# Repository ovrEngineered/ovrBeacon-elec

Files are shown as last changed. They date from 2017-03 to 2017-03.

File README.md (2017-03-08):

# ovrBeacon-elec

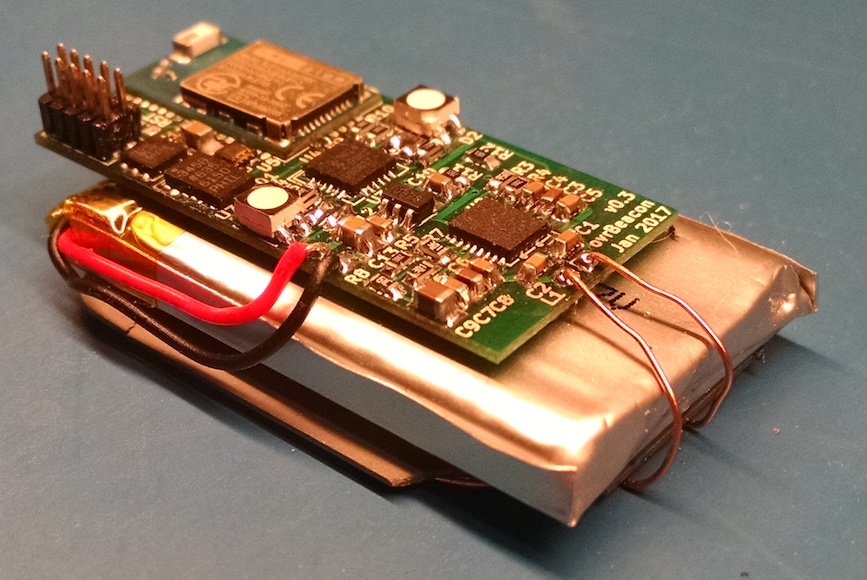
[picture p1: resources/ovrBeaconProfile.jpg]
ovrBeacon Profile


This project contains an open-source implementation of a Bluetooth Low Energy sensor beacon.
The beacon has the following features:
 - Integrated temperature sensor
 - Integrated light sensor
 - Integrated accelerometer
 - Remotely controlled LEDs
 - Wireless charging via Qi standard
 
Note: this repository contains the schematics and PCB design. The firmware repository is located [here](https://github.com/ovrEngineered/ovrBeacon-fw).

## Physical Description
ovrBeacon Dimensions

| Height | Width | Depth w/ programming header | Depth w/o programming header |
| --- | --- | --- | --- |
| 1.85" (47mm) | 1.06" (27mm) | 0.57" (14.48mm) | 0.41" (10.41mm) |

## Parameters
| Parameter | Min  | Typical | Max | Units |
| --- | ---- | --- | --- | ----- |
| Temperature accuracy**  | - | +/- 1 | - | °C |
| Acceleration range | -16  | - | +16 | g |
| Acceleration resolution | - | 4 | - | mg |
| Light sensitivity | 0.01 | - | 64,000 | lux |
| Battery Capacity*** | - | 500 | - | mAh.  |
** accuracy can be increased with pin-compatible parts 

*** capacity can be increased with replacement batteries

## Links
 * [Schematic PDF](output/ovrBeacon_schematic.pdf)
 * [PCB Layout PDF](output/ovrBeacon_layout.pdf)

## Built With
 * [KiCad](http://kicad-pcb.org/)

## Versioning
We use [SemVer](http://semver.org/) for versioning. For the versions available, see the [tags on this repository](https://github.com/ovrEngineered/ovrBeacon-elec/tags). 

## License
This project is licensed under the MIT License:

> Permission is hereby granted, free of charge, to any person obtaining a copy of this software and associated documentation files (the "Software"), to deal in the Software without restriction, including without limitation the rights to use, copy, modify, merge, publish, distribute, sublicense, and/or sell copies of the Software, and to permit persons to whom the Software is furnished to do so, subject to the following conditions:
>
> The above copyright notice and this permission notice shall be included in all copies or substantial portions of the Software.
>
> THE SOFTWARE IS PROVIDED "AS IS", WITHOUT WARRANTY OF ANY KIND, EXPRESS OR IMPLIED, INCLUDING BUT NOT LIMITED TO THE WARRANTIES OF MERCHANTABILITY, FITNESS FOR A PARTICULAR PURPOSE AND NONINFRINGEMENT. IN NO EVENT SHALL THE AUTHORS OR COPYRIGHT HOLDERS BE LIABLE FOR ANY CLAIM, DAMAGES OR OTHER LIABILITY, WHETHER IN AN ACTION OF CONTRACT, TORT OR OTHERWISE, ARISING FROM, OUT OF OR IN CONNECTION WITH THE SOFTWARE OR THE USE OR OTHER DEALINGS IN THE SOFTWARE.

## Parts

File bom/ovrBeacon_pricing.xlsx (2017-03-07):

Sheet: Stock
Reference | Manufacturer | Man. Part Num. | Supplier | Supplier Part Num. | Quantity | Price (qty 1) | Subtotal (qty 1) | Price (qty 1000) | Subtotal (qty 1000)
U1 | BlueGiga | BLE113-A-M256K | Digi-Key | 1446-1035-1-ND | 1 | $11.49 | $11.49 | $6.948850 | $6.948850
R1 R5 R4 R9 R10 | Vishay_Dale | CRCW060310K0FKEA | Digi-Key | 541-10.0KHCT-ND | 5 | $0.10 | $0.50 | $0.003610 | $0.018050
C1 | TDK Corporation | C1608X7R1E154K080AA | Digi-Key | 445-5190-1-ND | 1 | $0.10 | $0.10 | $0.015150 | $0.015150
C2 | Murata | GRM188R71H222KA01D | Digi-Key | 490-1500-1-ND | 1 | $0.10 | $0.10 | $0.008820 | $0.008820
C6 C5 | Murata | GRM188R71E103KA01D | Digi-Key | 490-1520-1-ND | 2 | $0.10 | $0.20 | $0.005760 | $0.011520
C3 C8 | TDK Corporation | C1608X5R1E474K080AC | Digi-Key | 445-5144-1-ND | 2 | $0.15 | $0.30 | $0.027780 | $0.055560
C4 C7 | Murata | GRM188R71E223KA01D | Digi-Key | 490-9761-1-ND | 2 | $0.10 | $0.20 | $0.015450 | $0.030900
C9 | Murata | GRT21BR61E226ME13L | Digi-Key | 490-12389-1-ND | 1 | $0.58 | $0.58 | $0.187250 | $0.187250
R8 | Yageo | RC0603FR-0742K2L | Digi-Key | 311-42.2KHRCT-ND | 1 | $0.10 | $0.10 | $0.002330 | $0.002330
R6 R7 | Yageo | RC0603FR-07300RL | Digi-Key | 311-300HRCT-ND | 2 | $0.10 | $0.20 | $0.002330 | $0.004660
R3 | Yageo | RC0603FR-07953RL | Digi-Key | 311-953HRCT-ND | 1 | $0.10 | $0.10 | $0.002330 | $0.002330
C13 C11 | Murata | GRM21BR71A105KA01L | Digi-Key | 490-1695-1-ND | 2 | $0.11 | $0.22 | $0.020830 | $0.041660
C12 C10 | Murata | GRM188R71C104KA01D | Digi-Key | 490-1532-1-ND | 2 | $0.10 | $0.20 | $0.004730 | $0.009460
R14 R15 R16 R17 R18 R19 | Vishay_Dale | CRCW0603120RFKEA | Digi-Key | 541-120HCT-ND | 6 | $0.10 | $0.60 | $0.055400 | $0.332400
R11 | Vishay_Dale | CRCW060312K0FKEA | Digi-Key | 541-12.0KHCT-ND | 1 | $0.10 | $0.10 | $0.005540 | $0.005540
R12 | Vishay_Dale | CRCW06035K10FKEA | Digi-Key | 541-5.10KHCT-ND | 1 | $0.10 | $0.10 | $0.005540 | $0.005540
D1 D2 | Cree Inc. | CLV1A-FKB-CK1N1G1BB7R4S3 | Digi-Key | CLV1A-FKB-CK1N1G1BB7R4S3CT-ND | 2 | $0.74 | $1.48 | $0.442200 | $0.884400
L1 | Vishay Dale | IWAS3827ECEB100J50 | Digi-Key | 541-1695-ND | 1 | $3.39 | $3.39 | $1.695000 | $1.695000
U2 | Texas Instruments | BQ51050BRHLR | Digi-Key | 296-35066-1-ND | 1 | $4.23 | $4.23 | $2.116800 | $2.116800
U3 | Torex Semiconductor | XC6210B332MR-G | Digi-Key | 893-1075-1-ND | 1 | $0.88 | $0.88 | $0.351020 | $0.351020
U4 | NXP | PCA9624BS | Digi-Key | 568-5304-1-ND | 1 | $1.91 | $1.91 | $0.940910 | $0.940910
U5 | Lite-On | LTR-329ALS-01 | Digi-Key | 160-2160-1-ND | 1 | $1.08 | $1.08 | $0.431060 | $0.431060
U7 | Analog Devices | ADXL345BCCZ-RL | Digi-Key | ADXL345BCCZ-RLCT-ND | 1 | $7.86 | $7.86 | $4.459460 | $4.459460
J1 | Amphenol | 20021111-00010T4LF | Digi-Key | 609-3712-ND | 1 | $0.64 | $0.64 | $0.330990 | $0.330990
U6 | Silicon Labs | SI7050-A20-IM | Digi-Key | 336-3118-5-ND | 1 | $1.25 | $1.25 | $0.939300 | $0.939300
Battery |  |  |  |  | 1
PCB |  |  |  |  | 1 | $1.00 | $1.00 | $1.000000 | $1.000000
Assembly |  |  |  |  | 1 |  |  | $2.000000 | $2.000000
 |  |  |  |  |  | Total: | $38.81 |  | $22.83

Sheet: Variant - No Accelerometer
Reference | Manufacturer | Man. Part Num. | Supplier | Supplier Part Num. | Quantity | Price (qty 1) | Subtotal (qty 1) | Price (qty 1000) | Subtotal (qty 1000)
U1 | BlueGiga | BLE113-A-M256K | Digi-Key | 1446-1035-1-ND | 1 | $11.49 | $11.49 | $6.948850 | $6.948850
R1 R5 R4 R9 R10 | Vishay_Dale | CRCW060310K0FKEA | Digi-Key | 541-10.0KHCT-ND | 5 | $0.10 | $0.50 | $0.003610 | $0.018050
C1 | TDK Corporation | C1608X7R1E154K080AA | Digi-Key | 445-5190-1-ND | 1 | $0.10 | $0.10 | $0.015150 | $0.015150
C2 | Murata | GRM188R71H222KA01D | Digi-Key | 490-1500-1-ND | 1 | $0.10 | $0.10 | $0.008820 | $0.008820
C6 C5 | Murata | GRM188R71E103KA01D | Digi-Key | 490-1520-1-ND | 2 | $0.10 | $0.20 | $0.005760 | $0.011520
C3 C8 | TDK Corporation | C1608X5R1E474K080AC | Digi-Key | 445-5144-1-ND | 2 | $0.15 | $0.30 | $0.027780 | $0.055560
C4 C7 | Murata | GRM188R71E223KA01D | Digi-Key | 490-9761-1-ND | 2 | $0.10 | $0.20 | $0.015450 | $0.030900
C9 | Murata | GRT21BR61E226ME13L | Digi-Key | 490-12389-1-ND | 1 | $0.58 | $0.58 | $0.187250 | $0.187250
R8 | Yageo | RC0603FR-0742K2L | Digi-Key | 311-42.2KHRCT-ND | 1 | $0.10 | $0.10 | $0.002330 | $0.002330
R6 R7 | Yageo | RC0603FR-07300RL | Digi-Key | 311-300HRCT-ND | 2 | $0.10 | $0.20 | $0.002330 | $0.004660
R3 | Yageo | RC0603FR-07953RL | Digi-Key | 311-953HRCT-ND | 1 | $0.10 | $0.10 | $0.002330 | $0.002330
C13 C11 | Murata | GRM21BR71A105KA01L | Digi-Key | 490-1695-1-ND | 2 | $0.11 | $0.22 | $0.020830 | $0.041660
C12 C10 | Murata | GRM188R71C104KA01D | Digi-Key | 490-1532-1-ND | 2 | $0.10 | $0.20 | $0.004730 | $0.009460
R14 R15 R16 R17 R18 R19 | Vishay_Dale | CRCW0603120RFKEA | Digi-Key | 541-120HCT-ND | 6 | $0.10 | $0.60 | $0.055400 | $0.332400
R11 | Vishay_Dale | CRCW060312K0FKEA | Digi-Key | 541-12.0KHCT-ND | 1 | $0.10 | $0.10 | $0.005540 | $0.005540
R12 | Vishay_Dale | CRCW06035K10FKEA | Digi-Key | 541-5.10KHCT-ND | 1 | $0.10 | $0.10 | $0.005540 | $0.005540
D1 D2 | Cree Inc. | CLV1A-FKB-CK1N1G1BB7R4S3 | Digi-Key | CLV1A-FKB-CK1N1G1BB7R4S3CT-ND | 2 | $0.74 | $1.48 | $0.442200 | $0.884400
L1 | Vishay Dale | IWAS3827ECEB100J50 | Digi-Key | 541-1695-ND | 1 | $3.39 | $3.39 | $1.695000 | $1.695000
U2 | Texas Instruments | BQ51050BRHLR | Digi-Key | 296-35066-1-ND | 1 | $4.23 | $4.23 | $2.116800 | $2.116800
U3 | Torex Semiconductor | XC6210B332MR-G | Digi-Key | 893-1075-1-ND | 1 | $0.88 | $0.88 | $0.351020 | $0.351020
U4 | NXP | PCA9624BS | Digi-Key | 568-5304-1-ND | 1 | $1.91 | $1.91 | $0.940910 | $0.940910
U5 | Lite-On | LTR-329ALS-01 | Digi-Key | 160-2160-1-ND | 1 | $1.08 | $1.08 | $0.431060 | $0.431060
U7 | Analog Devices | ADXL345BCCZ-RL | Digi-Key | ADXL345BCCZ-RLCT-ND | 0 | $7.86 | $0.00 | $4.459460 | $0.000000
J1 | Amphenol | 20021111-00010T4LF | Digi-Key | 609-3712-ND | 1 | $0.64 | $0.64 | $0.330990 | $0.330990
U6 | Silicon Labs | SI7050-A20-IM | Digi-Key | 336-3118-5-ND | 1 | $1.25 | $1.25 | $0.939300 | $0.939300
Battery |  |  |  |  | 1
PCB |  |  |  |  | 1 | $1.00 | $1.00 | $1.000000 | $1.000000
Assembly |  |  |  |  | 1 |  |  | $2.000000 | $2.000000
 |  |  |  |  |  | Total: | $30.95 |  | $18.37

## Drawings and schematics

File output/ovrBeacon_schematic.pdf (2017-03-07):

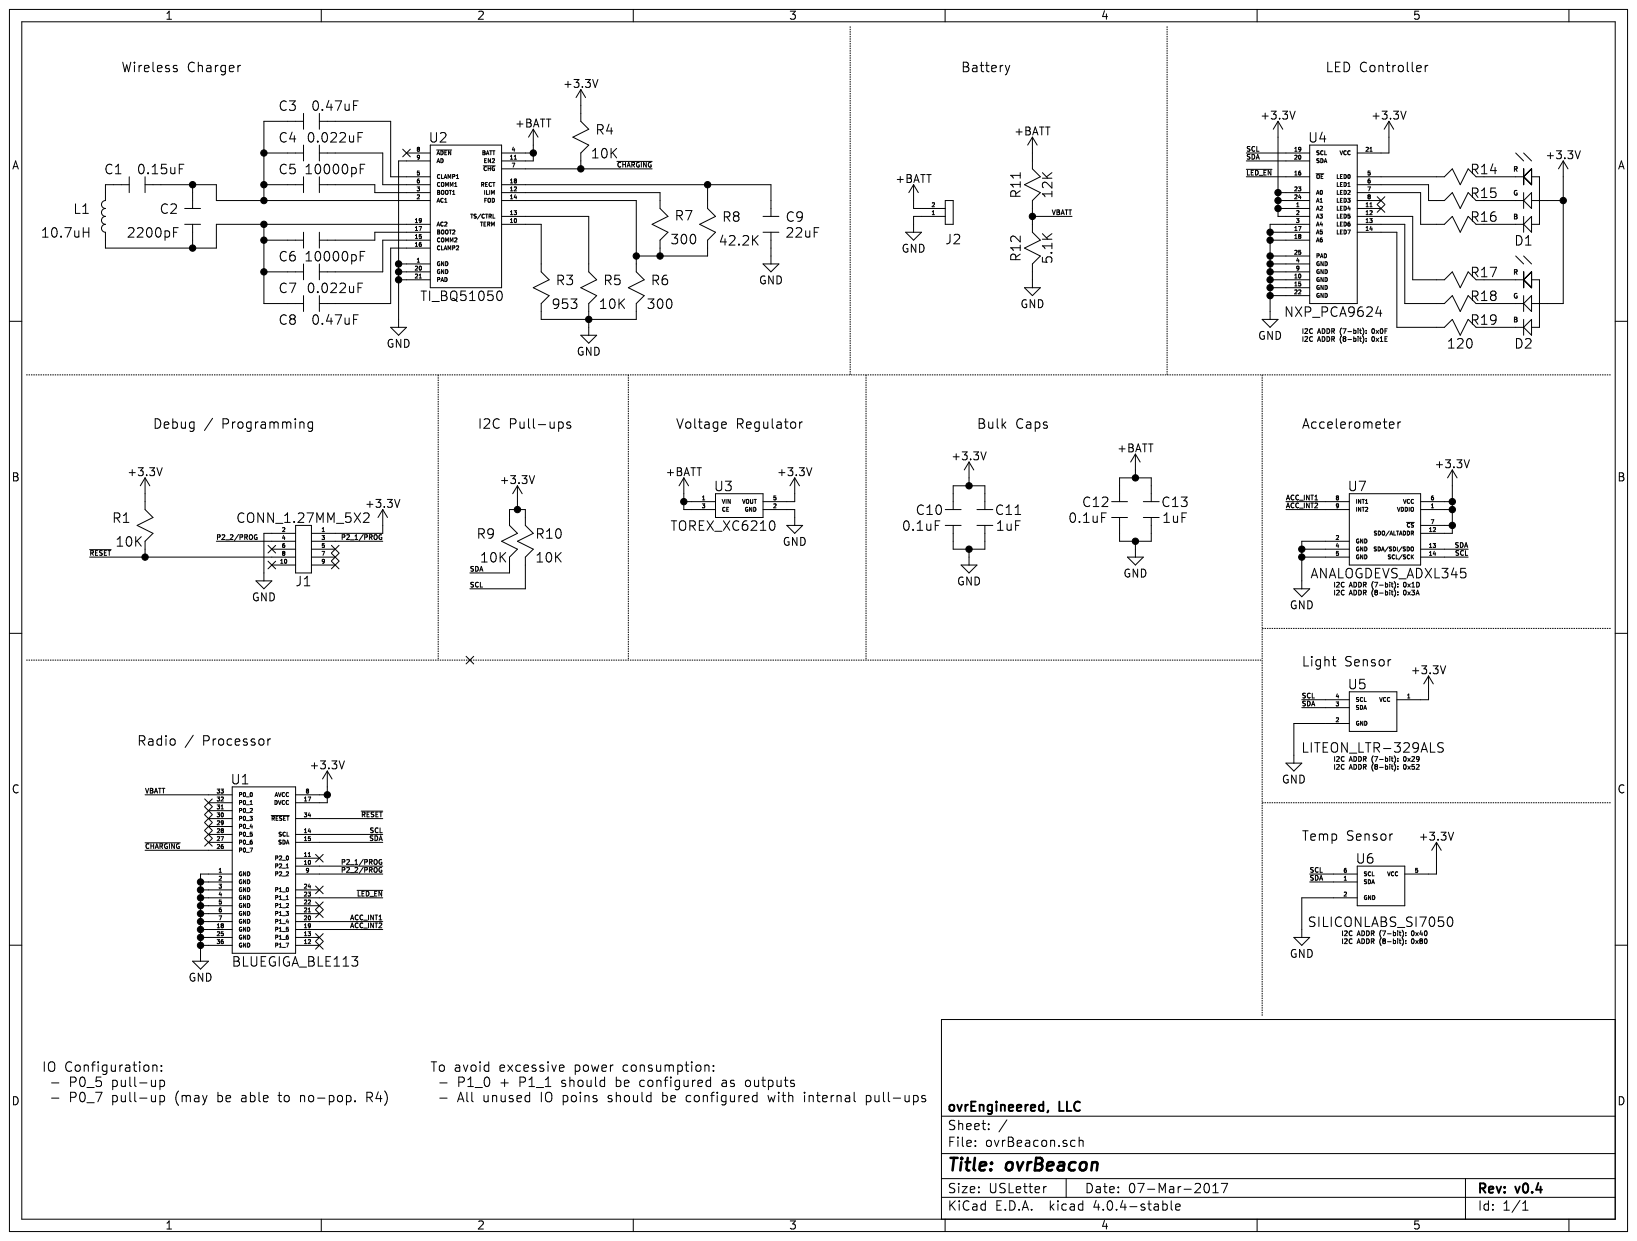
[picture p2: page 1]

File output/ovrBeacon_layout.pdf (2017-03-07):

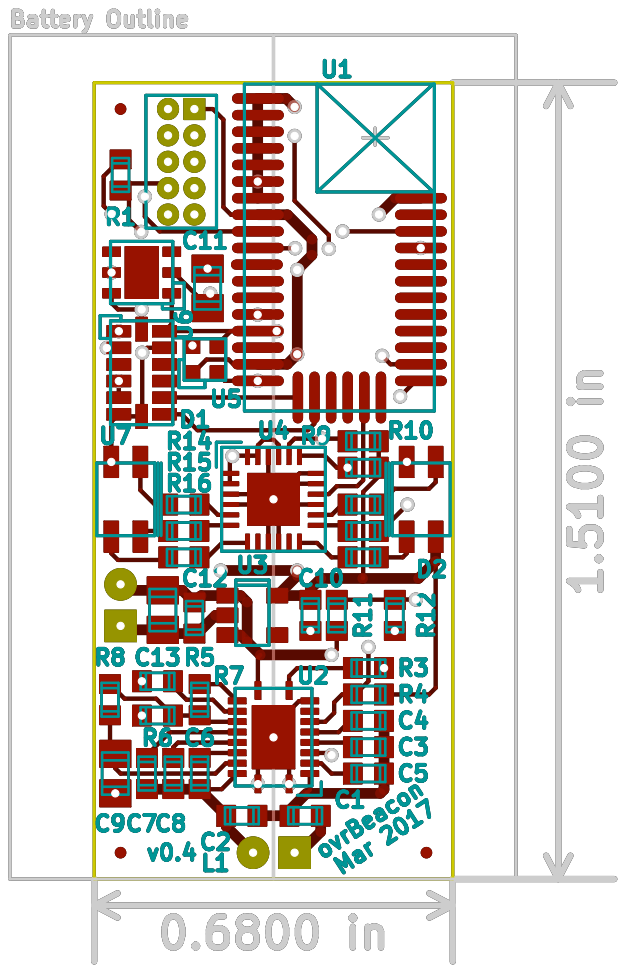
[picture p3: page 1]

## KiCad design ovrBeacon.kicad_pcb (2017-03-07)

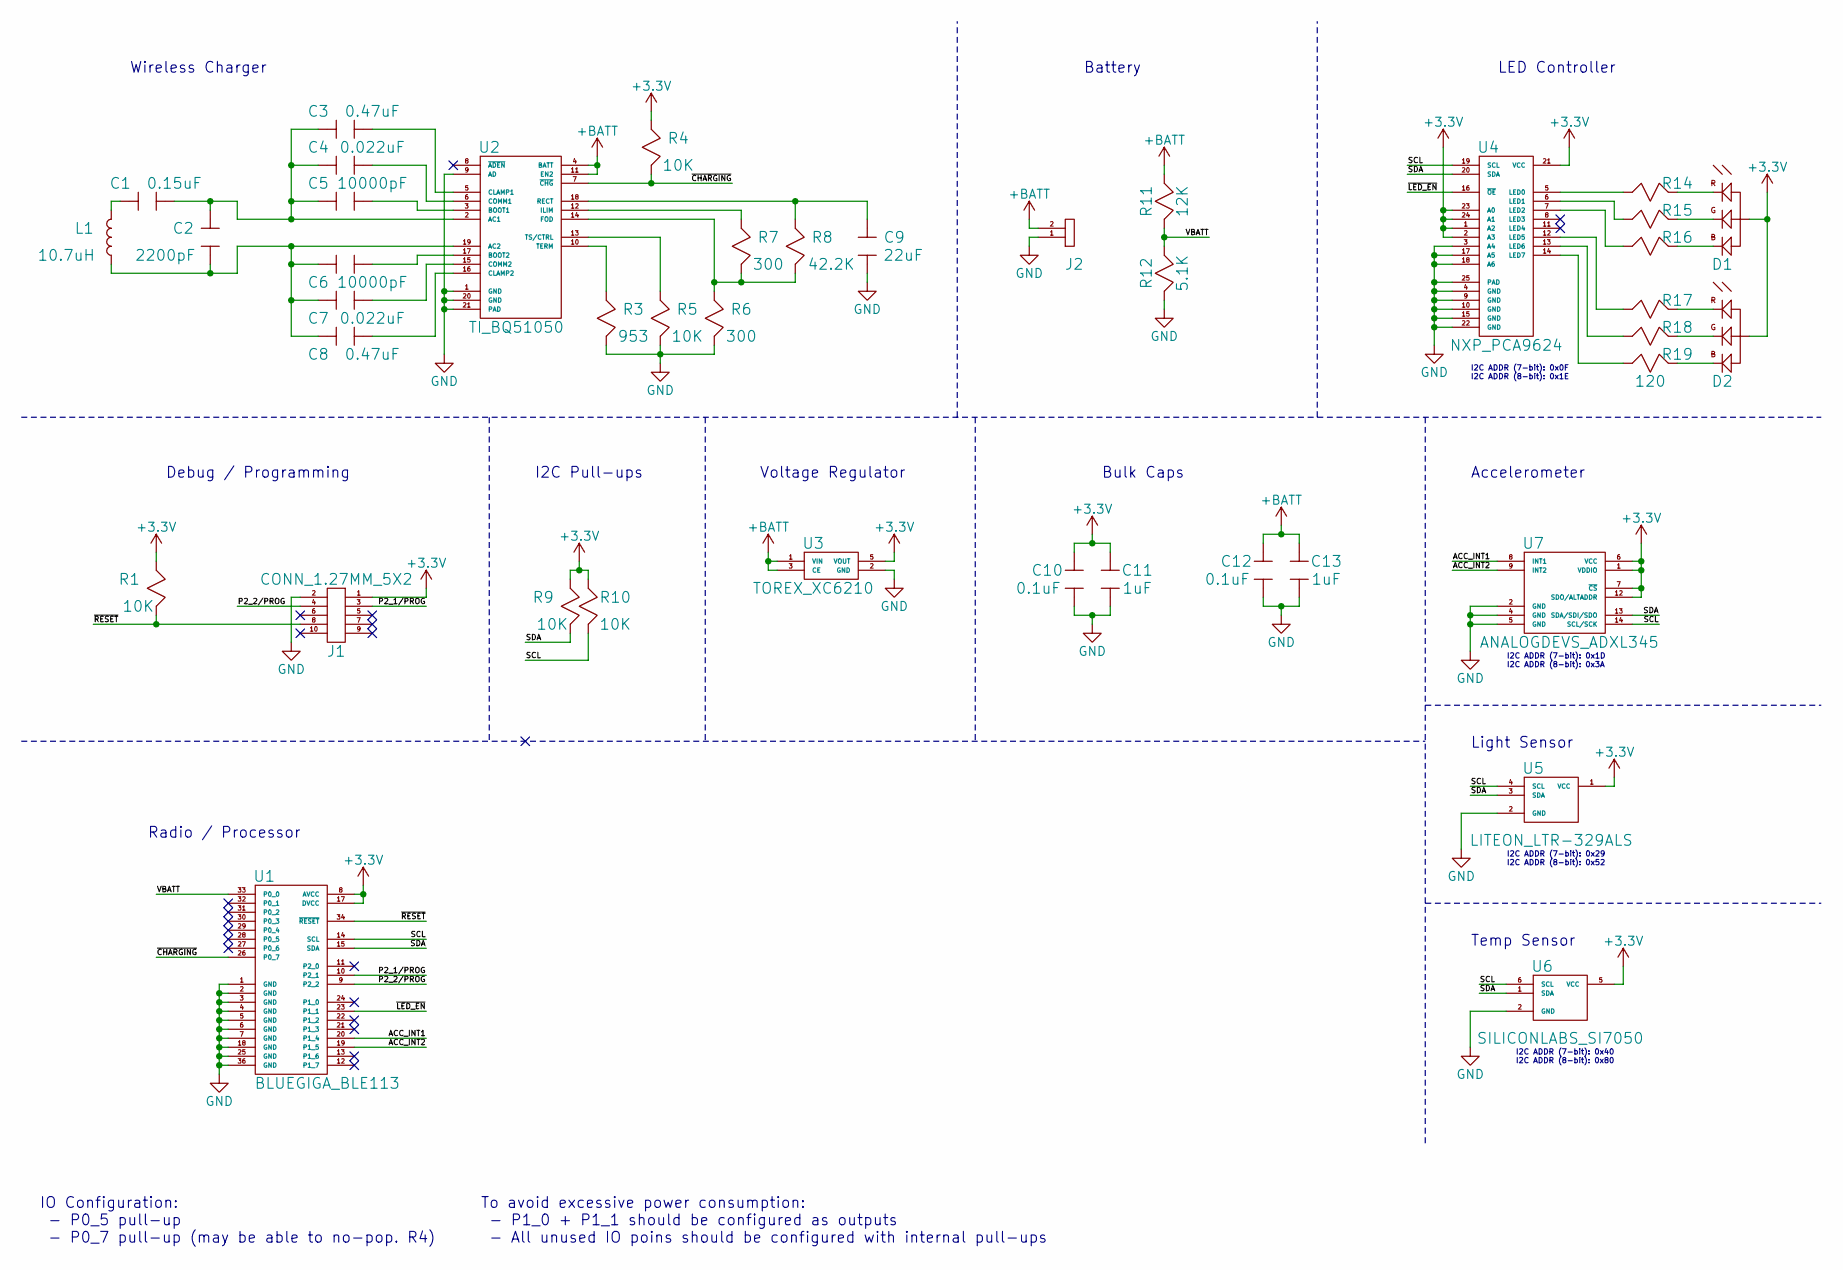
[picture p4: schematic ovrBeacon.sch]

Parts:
C1: C_0.15uF_25v_0603; C_0603; Man. Part Num. C1608X7R1E154K080AA
C2: C_2200pF_50v_0603; C_0603; Man. Part Num. GRM188R71H222KA01D
C3, C8: C_0.47uF_25v_0603; C_0603; Man. Part Num. C1608X5R1E474K080AC
C4, C7: C_0.022uF_25v_0603; C_0603; Man. Part Num. GRM188R71E223KA01D
C5, C6: C_10000pF_25v_0603; C_0603; Man. Part Num. GRM188R71E103KA01D
C9: C_22uF_25v_0805; C_0805; Man. Part Num. GRT21BR61E226ME13L
C10, C12: C_0.1uF_10v_0603; C_0603; Man. Part Num. GRM188R71C104KA01D
C11, C13: C_1uF_10v_0805; C_0805; Man. Part Num. GRM21BR71A105KA01L
D1, D2: CREE_CLV1A_FKB; Man. Part Num. CLV1A-FKB-CK1N1G1BB7R4S3
J1: CONN_1.27MM_5X2; 20021111-00010T4LF; Man. Part Num. 20021111-00010T4LF
J2: CONN_2MM_2; SIP_2MM_2; Man. Part Num. 951102-8622-AR
L1: QIRX_10.7uH; SIP_2MM_2; Man. Part Num. IWAS3827ECEB100J50
R1, R4, R5, R9, R10: R_10K_1%_0603; R_0603; Man. Part Num. CRCW060310K0FKEA
R3: R_953_1%_0603; R_0603; Man. Part Num. RC0603FR-07953RL
R6, R7: R_300_1%_0603; R_0603; Man. Part Num. RC0603FR-07300RL
R8: R_42.2K_1%_0603; R_0603; Man. Part Num. RC0603FR-0742K2L
R11: R_12K_1%_0603; R_0603; Man. Part Num. CRCW060312K0FKEA
R12: R_5.1K_1%_0603; R_0603; Man. Part Num. CRCW06035K10FKEA
R14, R15, R16, R17, R18, R19: R_120_1%_0603; R_0603; Man. Part Num. CRCW0603120RFKEA
U1: BLUEGIGA_BLE113; BLE113; Man. Part Num. BLE113-A-M256K
U2: TI_BQ51050; Man. Part Num. BQ51050BRHLR
U3: TOREX_XC6210; SOT-25-5; Man. Part Num. XC6210B332MR-G
U4: NXP_PCA9624; Man. Part Num. PCA9624BS,118
U5: LITEON_LTR-329ALS; Man. Part Num. LTR-329ALS-01
U6: SILICONLABS_SI7050; Man. Part Num. SI7050-A20-IM
U7: ANALOGDEVS_ADXL345; Man. Part Num. ADXL345BCCZ-RL

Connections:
+3V3: C10.1, C11.1, D1.2 (ANODE), D2.2 (ANODE), J1.1, R1.1, R4.1, R9.1, R10.1, U1.8 (AVCC), U1.17 (DVCC), U3.5 (VOUT), U4.1 (A2), U4.2 (A3), U4.21 (VCC), U4.23 (A0), U4.24 (A1), U5.1 (VCC), U6.5 (VCC), U7.1 (VDDIO), U7.6 (VCC), U7.7 (~CS), U7.12 (SDO/ALTADDR)
+BATT: C12.1, C13.1, J2.2, R11.1, U2.4 (BATT), U2.11 (EN2), U3.1 (VIN), U3.3 (CE)
/ACC_INT1: U1.20 (P1_4), U7.8 (INT1)
/ACC_INT2: U1.19 (P1_5), U7.9 (INT2)
/P2_1/PROG: J1.3, U1.10 (P2_1)
/P2_2/PROG: J1.4, U1.9 (P2_2)
/SCL: R10.2, U1.14 (SCL), U4.19 (SCL), U5.4 (SCL), U6.6 (SCL), U7.14 (SCL/SCK)
/SDA: R9.2, U1.15 (SDA), U4.20 (SDA), U5.3 (SDA), U6.1 (SDA), U7.13 (SDA/SDI/SDO)
/VBATT: R11.2, R12.1, U1.33 (P0_0)
/~CHARGING: R4.2, U1.26 (P0_7), U2.7 (~CHG)
/~LED_EN: U1.23 (P1_1), U4.16 (~OE)
/~RESET: J1.8, R1.2, U1.34 (~RESET)
GND: C9.2, C10.2, C11.2, C12.2, C13.2, J1.2, J2.1, R3.2, R5.2, R6.2, R12.2, U1.1 (GND), U1.2 (GND), U1.3 (GND), U1.4 (GND), U1.5 (GND), U1.6 (GND), U1.7 (GND), U1.18 (GND), U1.25 (GND), U1.36 (GND), U2.1 (GND), U2.9 (AD), U2.20 (GND), U2.21 (PAD), U3.2 (GND), U4.3 (A4), U4.4 (GND), U4.9 (GND), U4.10 (GND), U4.15 (GND), U4.17 (A5), U4.18 (A6), U4.22 (GND), U4.25 (PAD), U5.2 (GND), U6.2 (GND), U7.2 (GND), U7.4 (GND), U7.5 (GND)
unnamed: C1.1, L1.1
unnamed: C1.2, C2.1, C3.1, C4.1, C5.1, U2.2 (AC1)
unnamed: C2.2, C6.1, C7.1, C8.1, L1.2, U2.19 (AC2)
unnamed: C3.2, U2.5 (CLAMP1)
unnamed: C4.2, U2.6 (COMM1)
unnamed: C5.2, U2.3 (BOOT1)
unnamed: C6.2, U2.17 (BOOT2)
unnamed: C7.2, U2.15 (COMM2)
unnamed: C8.2, U2.16 (CLAMP2)
unnamed: C9.1, R8.1, U2.18 (RECT)
unnamed: D1.1 (CATHODE_RED), R14.2
unnamed: D1.3 (CATHODE_BLUE), R16.2
unnamed: D1.4 (CATHOD_GREEN), R15.2
unnamed: D2.1 (CATHODE_RED), R17.2
unnamed: D2.3 (CATHODE_BLUE), R19.2
unnamed: D2.4 (CATHOD_GREEN), R18.2
unnamed: R3.1, U2.10 (TERM)
unnamed: R5.1, U2.13 (TS/CTRL)
unnamed: R6.1, R7.1, R8.2, U2.14 (FOD)
unnamed: R7.2, U2.12 (ILIM)
unnamed: R14.1, U4.5 (LED0)
unnamed: R15.1, U4.6 (LED1)
unnamed: R16.1, U4.7 (LED2)
unnamed: R17.1, U4.12 (LED5)
unnamed: R18.1, U4.13 (LED6)
unnamed: R19.1, U4.14 (LED7)

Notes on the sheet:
Debug / Programming
Radio / Processor
I2C ADDR (7-bit): 0x29 I2C ADDR (8-bit): 0x52
I2C ADDR (7-bit): 0x40 I2C ADDR (8-bit): 0x80
I2C ADDR (7-bit): 0x1D I2C ADDR (8-bit): 0x3A
I2C ADDR (7-bit): 0x0F I2C ADDR (8-bit): 0x1E
I2C Pull-ups
Wireless Charger
Battery
LED Controller
Accelerometer
Light Sensor
Temp Sensor
Voltage Regulator
Bulk Caps
To avoid excessive power consumption: - P1_0 + P1_1 should be configured as outputs - All unused IO poins should be configured with internal pull-ups
IO Configuration: - P0_5 pull-up - P0_7 pull-up (may be able to no-pop. R4)

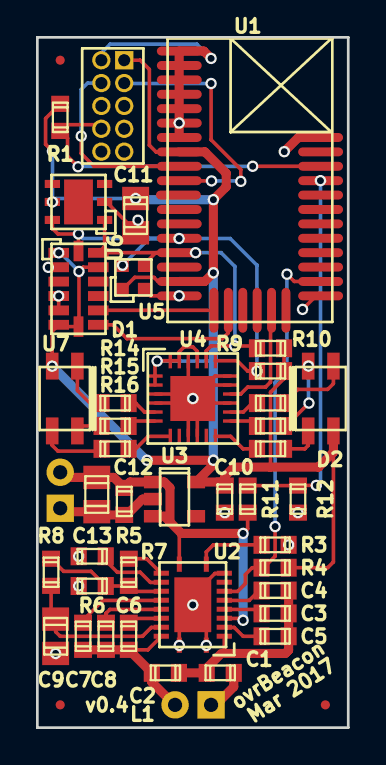
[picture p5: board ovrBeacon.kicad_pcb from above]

Board: 2 copper layers, 17.3 x 38.4 mm, 45 parts (0 on the bottom side), 39 nets.

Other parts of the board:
FID1, FID2, FID3: fiducial

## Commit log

2016-07-31 added KiCAD externals
2017-01-04 initial commit of version 0.3…passed DFM, waiting for manufacture review
    [ovrBeacon-B.Cu.gbl, ovrBeacon-B.Mask.gbs, ovrBeacon-B.SilkS.gbo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]
2017-01-12 As manufactured
    [BOM - ovrBeacon.ods, BillOfMaterials.csv]
2017-02-27 Moved BOM, added pricing, added schematic and layout PDF
    [ovrBeacon_BOM.csv, ovrBeacon_pricing.xlsx]
2017-03-07 Fixed redlines from v0.3, added fiducials for pick and place…getting ready to start adjusting component centers for pick and place
    [ovrBeacon.kicad_pcb, ovrBeacon.sch]
2017-03-07 Adjusted component centers and orientation for pick and place
    [ovrBeacon.kicad_pcb]
2017-03-07 ready for fabrication w/ fiducials, redlines from v0.3, and pick and place file
    [ovrBeacon-B.Cu.gbl, ovrBeacon-B.Mask.gbs, ovrBeacon-B.SilkS.gbo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]
2017-03-07 Updated pricing document w/ variants
    [ovrBeacon_pricing.xlsx]
